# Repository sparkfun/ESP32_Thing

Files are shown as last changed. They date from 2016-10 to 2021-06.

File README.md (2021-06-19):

SparkFun ESP32 Thing
========================================

SparkFun ESP32 Thing (https://www.sparkfun.com/products/13907)

[*SparkFun ESP32 Thing (DEV-13907)*](https://www.sparkfun.com/products/13907)

The [SparkFun ESP32 Thing](https://www.sparkfun.com/products/13907) is a comprehensive development platform for Espressif’s ESP32, their super-charged version of the popular ESP8266. Like the 8266, the ESP32 is a WiFi-compatible microcontroller but adds nearly 30 I/O pins. The ESP32’s power and versatility will make it the foundation of IoT and connected projects for many years to come.

Why the name? We lovingly call it the “Thing” because it's the perfect foundation for your Internet of Things project. The Thing does everything from turning on an LED to posting data with your chosen platform, and can be programmed just like any microcontroller. You can even program the Thing through the Arduino IDE by installing the [ESP32 Arduino Core](https://learn.sparkfun.com/tutorials/esp32-thing-hookup-guide#installing-the-esp32-arduino-core).

The SparkFun ESP32 Thing equips the ESP32 with everything necessary to program, run and develop on the wonderchip. In addition to the WiFi SoC, the Thing includes an FTDI FT231x, which converts USB to serial, and allows your computer to program and communicate with the microcontroller. It also features a LiPo charger, so your ESP32 project can be battery-powered and truly wireless. Additionally, the board includes a handful of LEDs and buttons to aid in your development.

Repository Contents
-------------------

* **/Hardware** - Eagle design files (.brd, .sch)
* **/Production** - Production panel files (.brd)

Documentation
--------------
* **[Hookup Guide](https://learn.sparkfun.com/tutorials/esp32-thing-hookup-guide)** - Basic hookup guide for the ESP32 Thing.
* **[SparkFun Fritzing repo](https://github.com/sparkfun/Fritzing_Parts)** - Fritzing diagrams for SparkFun products.
* **[SparkFun 3D Model repo](https://github.com/sparkfun/3D_Models)** - 3D models of SparkFun products. 
* **[SparkFun Graphical Datasheets](https://github.com/sparkfun/Graphical_Datasheets)** -Graphical Datasheets for various SparkFun products.

Product Versions
----------------
* [DEV-13907](https://www.sparkfun.com/products/13907) - Initial release of the ESP32 Thing.

Version History
---------------
* [V_1.0](https://github.com/sparkfun/ESP32_Thing/releases/tag/V_1.0) - Initial release of the ESP32 Thing

License Information
-------------------

This product is _**open source**_! 

Please review the LICENSE.md file for license information. 

If you have any questions or concerns on licensing, please contact technical support on our [SparkFun forums](https://forum.sparkfun.com/viewforum.php?f=152).

Distributed as-is; no warranty is given.

- Your friends at SparkFun.

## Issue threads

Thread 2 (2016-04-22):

ESP31 Device in sch needs value updated to ESP32

SFE-KADE, 2016-04-22:

ToniCorinne, 2017-02-08:
This board is live. Closing the issue as resolved.

Closed 2017-02-08.

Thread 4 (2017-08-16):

Provide KiCAD modules and library

trycoon, 2017-08-16:
Many DIY builders use Open Source CAD programs (KiCAD for one) instead of licensed programs like Eagle. It would be very nice if there where a KiCAD module and library of Sparkfun ESP32 Thing for us to use! There is a Eagle script plugin that may help converting your existing Eagle schematics to a KiCAD  module/library: https://github.com/lachlanA/eagle-to-kicad
Could you please give it a try, since I don't have a Eagle license to try it myself.
Thanks!

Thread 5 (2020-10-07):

Provide mounting holes

TheChain01, 2020-10-07:
It would be really good if this board could provide some mounting holes in order to secure it in our projects. Right now we would have to solder the board onto another protoboard with mounting holes in order to secure it in place.

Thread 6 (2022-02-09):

Isn't Q1 connected backwards?

kuba2k2, 2022-02-09:
The P-channel MOSFET for switching VIN from USB or battery seems to have its drain and source swapped. This makes the circuit always use the battery voltage, when USB drops below that 4.2V. Since this isn't usually the case, that mostly isn't a problem, but it may occur in some cases, that USB provides such a low voltage that the ESP is powered half from the battery, which may trick the charger into thinking the battery is not fully charged, which may result in overcharging. I am no expert, but I think this is a problem that needs to be fixed.
I was trying to use the voltage switch from the Thing's schematic, implemented it already in my layout and then it came out to be wrong.. without D2, Q1 will always be either saturated or the current will flow through the body diode. Unless that's expected to work this way.

Edit: it's implemented the same way in RP2040 Thing, ESP32-S2, ESP8266 and probably other Things. Please, correct me if I'm wrong (which would be absolutely expected).

Closed 2022-02-09.

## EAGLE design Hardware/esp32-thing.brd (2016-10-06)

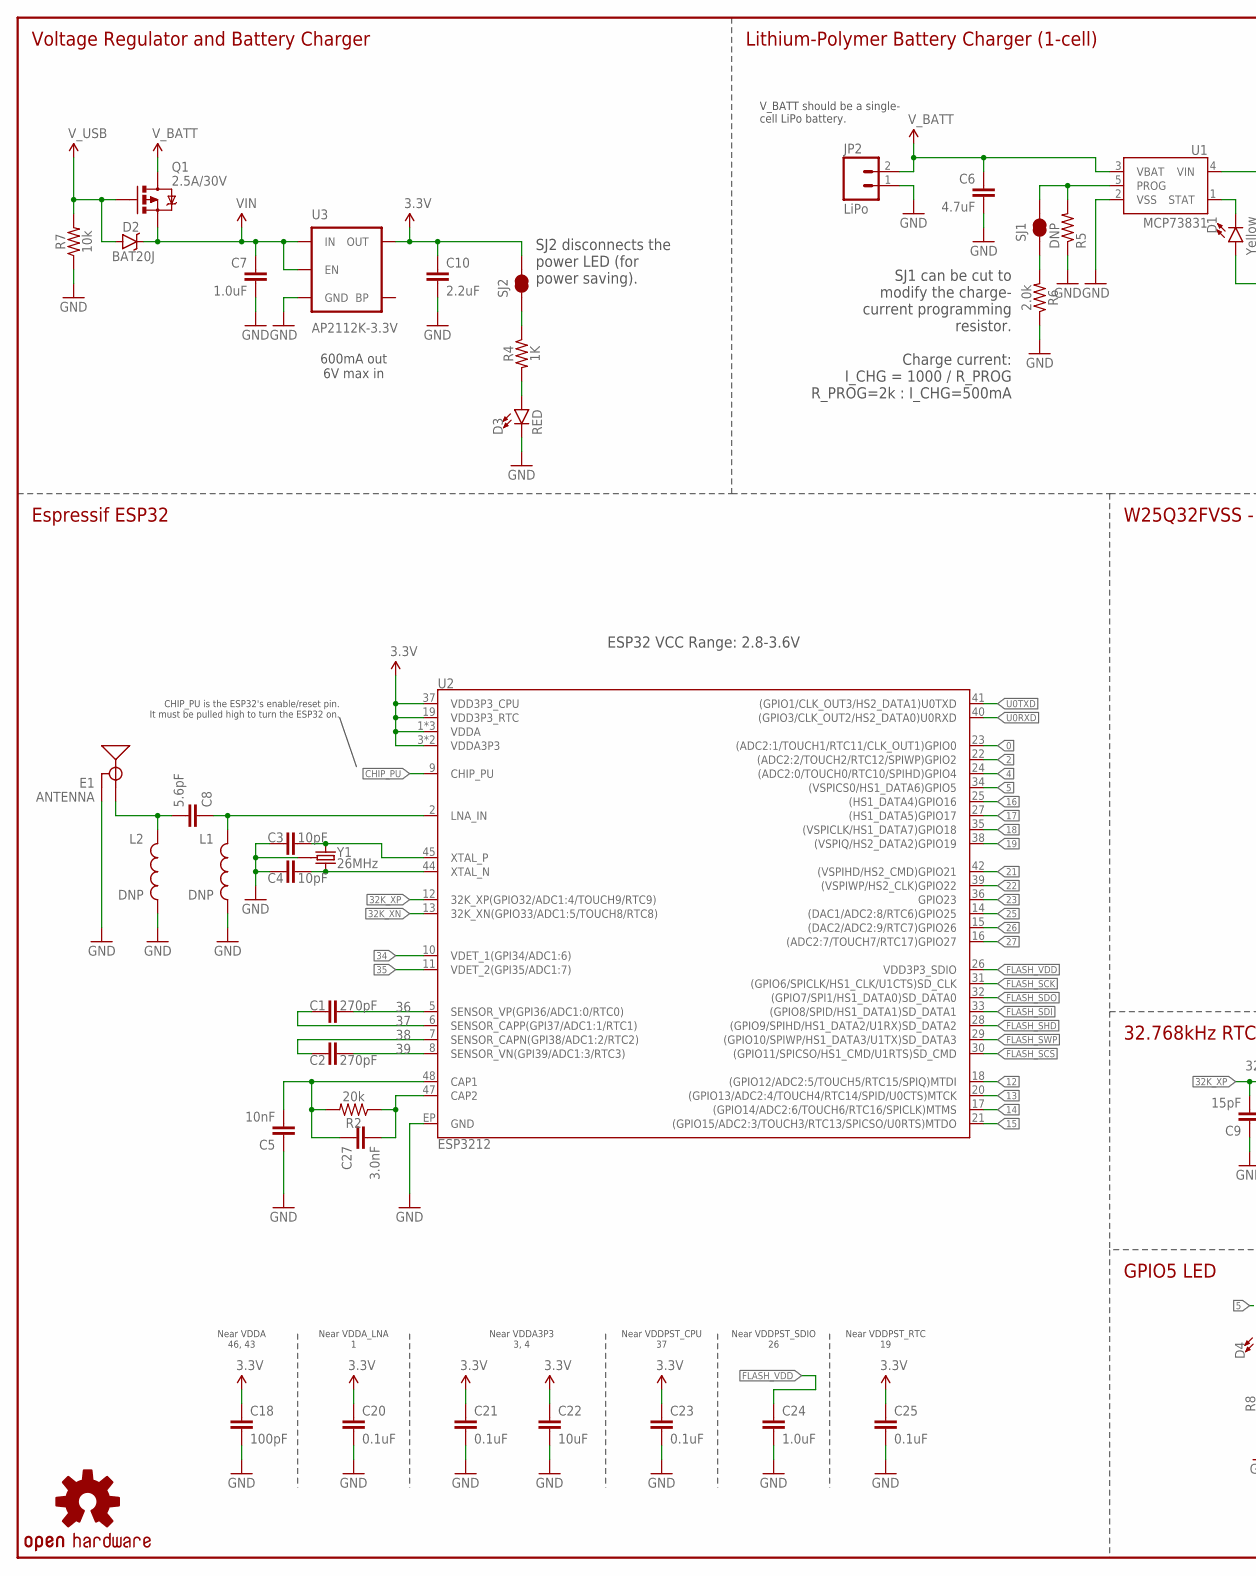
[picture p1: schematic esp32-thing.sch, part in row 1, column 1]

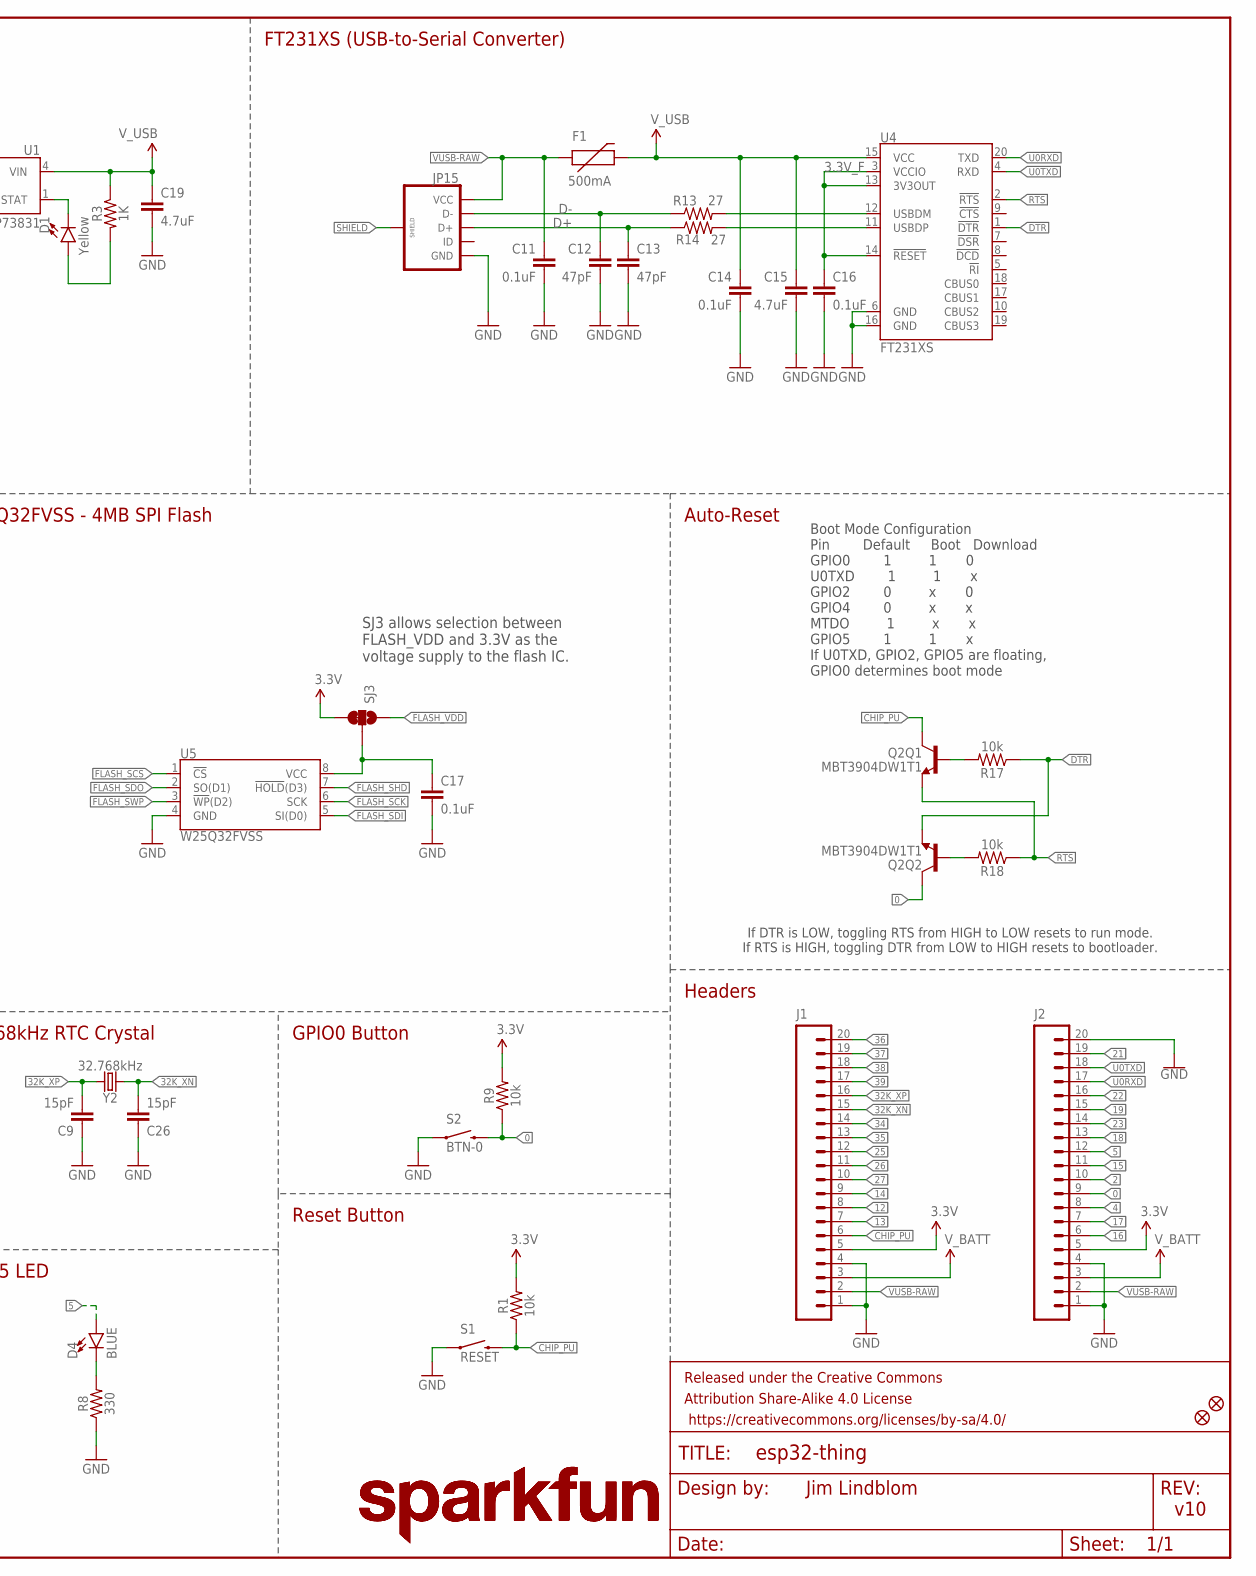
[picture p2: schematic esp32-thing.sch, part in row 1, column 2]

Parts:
C1, C2: 270pF; 0603
C3, C4: 10pF; 0603
C5: 10nF; 0603
C6, C19: 4.7uF; 0603
C7: 1.0uF; 0805
C8: 5.6pF; 0603
C9, C26: 15pF; 0603
C10: 2.2uF; 0603
C11, C14, C16, C17, C20, C21, C23, C25: 0.1uF; 0603
C12, C13: 47pF; 0603
C15: 4.7uF; 0603-CAP
C18: 100pF; 0603
C22: 10uF; 0603
C24: 1.0uF; 0603
C27: 3.0nF; 0603
D1: Yellow; LED-0603
D2: BAT20J; SOD-323
D3: RED; LED-0603
D4: BLUE; LED-0603
E1: ANTENNA; TRACE_ANTENNA_2.4GHZ_25.7MM_TUNED
F1: 500mA; PTC-1206
FD1, FD2: FIDUCIALUFIDUCIAL; MICRO-FIDUCIAL
FRAME1: FRAME-LEDGER; CREATIVE_COMMONS
J1, J2: M20NOSILK; 1X20_NOSILK
JP2: LiPo; JST-2-PTH
JP15: USB_MICROB_PLUGCONN-11752; USB-B-MICRO-SMD_V03
L1, L2: DNP; 0603
LOGO1, LOGO3: SFE_LOGO_NAME.2_INCH; SFE_LOGO_NAME_.2
LOGO2: OSHW-LOGOMINI; OSHW-LOGO-MINI
Q1: 2.5A/30V; SOT23-3
Q2: MBT3904DW1T1; SC70-6
R1, R7, R9, R17, R18: 10k; 0603
R2: 20k; 0603
R3, R4: 1K; 0603
R5: DNP; 1/6W-RES
R6: 2.0k; 0603
R8: 330; 0603
R13, R14: 27; 0603
S1: RESET; TACTILE_SWITCH_SMD_4.6X2.8MM
S2: BTN-0; TACTILE_SWITCH_SMD_4.6X2.8MM
SJ1, SJ2: JUMPER-PAD-2-NC_BY_TRACE; PAD-JUMPER-2-NC_BY_TRACE_YES_SILK
SJ3: JUMPER-PAD-3-2OF3_NC_BY_TRACE_SMALL; PAD-JUMPER-3-2OF3_NC_BY_TRACE_YES_SILK_FULL_BOX
U1: MCP73831; SOT23-5
U2: ESP3212; QFN48-0.4MM
U3: AP2112K-3.3V; SOT23-5
U4: FT231XS; SSOP20_L
U5: W25Q32FVSS; SOIC-8
Y1: 26MHz; CRYSTAL-SMD-3.2X2.5
Y2: 32.768kHz; CRYSTAL-SMD-3.2X1.5MM

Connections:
0: J2.9, Q2.6 (C), R9.1, S2.3 (2), S2.4 (2), U2.23 ((ADC2:1/TOUCH1/RTC11/CLK_OUT1)GPIO0)
2: J2.10, U2.22 ((ADC2:2/TOUCH2/RTC12/SPIWP)GPIO2)
3.3V: C10.1, C18.1, C20.1, C21.1, C22.1, C23.1, C25.1, J1.5, J2.5, R1.2, R9.2, SJ2.2, SJ3.3, U2.1 (VDDA), U2.3 (VDDA3P3), U2.4 (VDDA3P3), U2.19 (VDD3P3_RTC), U2.37 (VDD3P3_CPU), U2.43 (VDDA), U2.46 (VDDA), U3.5 (OUT)
3.3V_F: C16.1, U4.3 (VCCIO), U4.13 (3V3OUT), U4.14 (!RESET)
4: J2.8, U2.24 ((ADC2:0/TOUCH0/RTC10/SPIHD)GPIO4)
5: D4.A, J2.12, U2.34 ((VSPICS0/HS1_DATA6)GPIO5)
12: J1.8, U2.18 ((GPIO12/ADC2:5/TOUCH5/RTC15/SPIQ)MTDI)
13: J1.7, U2.20 ((GPIO13/ADC2:4/TOUCH4/RTC14/SPID/U0CTS)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)
14: J1.9, U2.17 ((GPIO14/ADC2:6/TOUCH6/RTC16/SPICLK)MTMS)
15: J2.11, U2.21 ((GPIO15/ADC2:3/TOUCH3/RTC13/SPICSO/U0RT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)
16: J2.6, U2.25 ((HS1_DATA4)GPIO16)
17: J2.7, U2.27 ((HS1_DATA5)GPIO17)
18: J2.13, U2.35 ((VSPICLK/HS1_DATA7)GPIO18)
19: J2.15, U2.38 ((VSPIQ/HS2_DATA2)GPIO19)
21: J2.19, U2.42 ((VSPIHD/HS2_CMD)GPIO21)
22: J2.16, U2.39 ((VSPIWP/HS2_CLK)GPIO22)
23: J2.14, U2.36 (GPIO23)
25: J1.12, U2.14 ((DAC1/ADC2:8/RTC6)GPIO25)
26: J1.11, U2.15 ((DAC2/ADC2:9/RTC7)GPIO26)
27: J1.10, U2.16 ((ADC2:7/TOUCH7/RTC17)GPIO27)
32K_XN: C26.2, J1.15, U2.13 (32K_XN(GPIO33/ADC1:5/TOUCH8/RTC8)), Y2.P$2 (2)
32K_XP: C9.2, J1.16, U2.12 (32K_XP(GPIO32/ADC1:4/TOUCH9/RTC9)), Y2.P$1 (1)
34: J1.14, U2.10 (VDET_1(GPI34/ADC1:6))
35: J1.13, U2.11 (VDET_2(GPI35/ADC1:7))
36: C1.2, J1.20, U2.5 (SENSOR_VP(GPI36/ADC1:0/RTC0))
37: C1.1, J1.19, U2.6 (SENSOR_CAPP(GPI37/ADC1:1/RTC1))
38: C2.1, J1.18, U2.7 (SENSOR_CAPN(GPI38/ADC1:2/RTC2))
39: C2.2, J1.17, U2.8 (SENSOR_VN(GPI39/ADC1:3/RTC3))
CAP_10N: C5.2, C27.1, R2.2, U2.48 (CAP1)
CHIP_PU: J1.6, Q2.3 (C), R1.1, S1.3 (2), S1.4 (2), U2.9 (CHIP_PU)
D+: C13.1, JP15.D+, R14.1
D-: C12.1, JP15.D-, R13.1
DTR: Q2.1 (E), R17.1, U4.1 (!DTR)
FLASH_SCK: U2.31 ((GPIO6/SPICLK/HS1_CLK/U1CTS)SD_CLK), U5.6 (SCK)
FLASH_SCS: U2.30 ((GPIO11/SPICSO/HS1_CMD/U1RTS)SD_CMD), U5.1 (!CS!)
FLASH_SDI: U2.33 ((GPIO8/SPID/HS1_DATA1)SD_DATA1), U5.5 (SI(D0))
FLASH_SDO: U2.32 ((GPIO7/SPI1/HS1_DATA0)SD_DATA0), U5.2 (SO(D1))
FLASH_SHD: U2.28 ((GPIO9/SPIHD/HS1_DATA2/U1RX)SD_DATA2), U5.7 (!HOLD!(D3))
FLASH_SWP: U2.29 ((GPIO10/SPIWP/HS1_DATA3/U1TX)SD_DATA3), U5.3 (!WP!(D2))
FLASH_VDD: C24.1, SJ3.1, U2.26 (VDD3P3_SDIO)
GND: C3.1, C4.1, C5.1, C6.2, C7.2, C9.1, C10.2, C11.2, C12.2, C13.2, C14.2, C15.2, C16.2, C17.2, C18.2, C19.2, C20.2, C21.2, C22.2, C23.2, C24.2, C25.2, C26.1, D3.C, E1.GND, E1.GND2 (GND), J1.1, J1.4, J2.1, J2.4, J2.20, JP2.1, JP15.GND, L1.2, L2.2, R5.1, R6.1, R7.1, R8.1, S1.1, S1.2 (1), S2.1, S2.2 (1), U1.2 (VSS), U2.EP (GND), U3.2 (GND), U4.6 (GND), U4.16 (GND), U5.4 (GND), Y1.2 (GND), Y1.4 (GND)
LNA_IN: C8.1, L1.1, U2.2 (LNA_IN)
unnamed: D4.C, R8.2
unnamed: D3.A, R4.2
unnamed: R4.1, SJ2.1
unnamed: C27.2, R2.1, U2.47 (CAP2)
unnamed: R13.2, U4.12 (USBDM)
unnamed: R14.2, U4.11 (USBDP)
unnamed: D1.C, U1.1 (STAT)
unnamed: Q2.5 (B), R17.2
unnamed: C17.1, SJ3.2, U5.8 (VCC)
unnamed: Q2.2 (B), R18.2
unnamed: C3.2, U2.45 (XTAL_P), Y1.1
unnamed: R5.2, SJ1.2, U1.5 (PROG)
unnamed: C4.2, U2.44 (XTAL_N), Y1.3 (2)
unnamed: R6.2, SJ1.1
unnamed: D1.A, R3.2
RTS: Q2.4 (E), R18.1, U4.2 (!RTS)
SHIELD: JP15.SHIELD1 (SHIELD), JP15.SHIELD2 (SHIELD), JP15.SHIELD3 (SHIELD)
TRACE_ANT: C8.2, E1.ANT (SIGNAL), L2.1
U0RXD: J2.17, U2.40 ((GPIO3/CLK_OUT2/HS2_DATA0)U0RXD), U4.20 (TXD)
U0TXD: J2.18, U2.41 ((GPIO1/CLK_OUT3/HS2_DATA1)U0TXD), U4.4 (RXD)
VIN: C7.1, D2.C, Q1.2 (S), U3.1 (IN), U3.3 (EN)
VUSB-RAW: C11.1, F1.1, J1.2, J2.2, JP15.VBUS (VCC)
V_BATT: C6.1, J1.3, J2.3, JP2.2, Q1.3 (D), U1.3 (VBAT)
V_USB: C14.1, C15.1, C19.1, D2.A, F1.2, Q1.1 (G), R3.1, R7.2, U1.4 (VIN), U4.15 (VCC)

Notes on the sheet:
Boot Mode Configuration Pin Default Boot Download GPIO0 1 1 0 U0TXD 1 1 x GPIO2 0 x 0 GPIO4 0 x x MTDO 1 x x GPIO5 1 1 x If U0TXD, GPIO2, GPIO5 are floating, GPIO0 determines boot mode
FT231XS (USB-to-Serial Converter)
V_BATT should be a single- cell LiPo battery.
Charge current: I_CHG = 1000 / R_PROG R_PROG=2k : I_CHG=500mA
Voltage Regulator and Battery Charger
SJ1 can be cut to modify the charge- current programming resistor.
Lithium-Polymer Battery Charger (1-cell)
600mA out 6V max in
Auto-Reset
Near VDDA 46, 43
Near VDDA_LNA 1
Near VDDA3P3 3, 4
Near VDDPST_CPU 37
Near VDDPST_SDIO 26
Near VDDPST_RTC 19
Espressif ESP32
W25Q32FVSS - 4MB SPI Flash
32.768kHz RTC Crystal
GPIO0 Button
Reset Button
GPIO5 LED
Headers
v10
Jim Lindblom
ESP32 VCC Range: 2.8-3.6V
SJ3 allows selection between FLASH_VDD and 3.3V as the voltage supply to the flash IC.
SJ2 disconnects the power LED (for power saving).
If DTR is LOW, toggling RTS from HIGH to LOW resets to run mode. If RTS is HIGH, toggling DTR from LOW to HIGH resets to bootloader.
CHIP_PU is the ESP32's enable/reset pin. It must be pulled high to turn the ESP32 on.

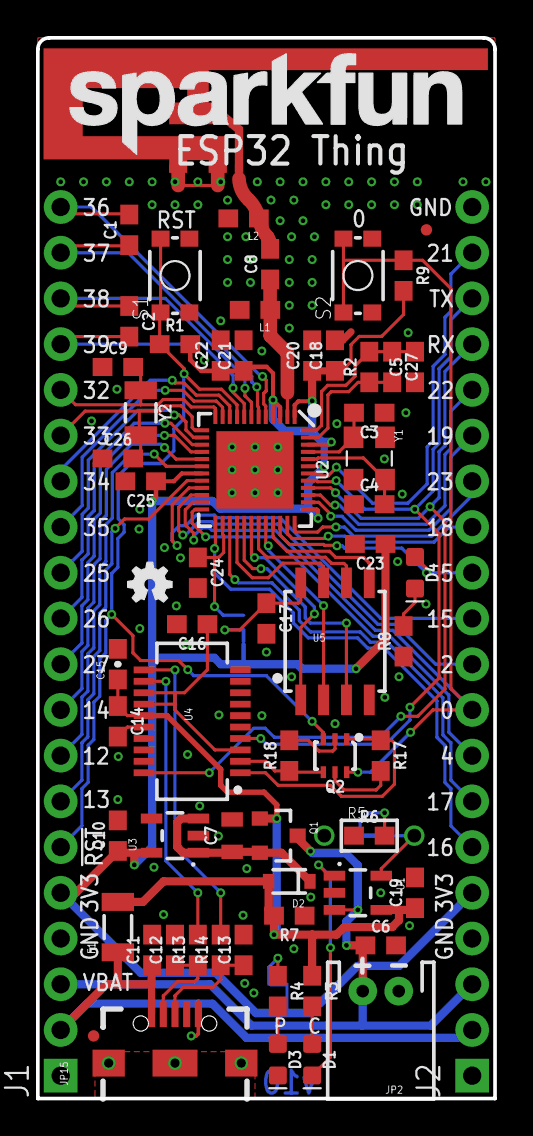
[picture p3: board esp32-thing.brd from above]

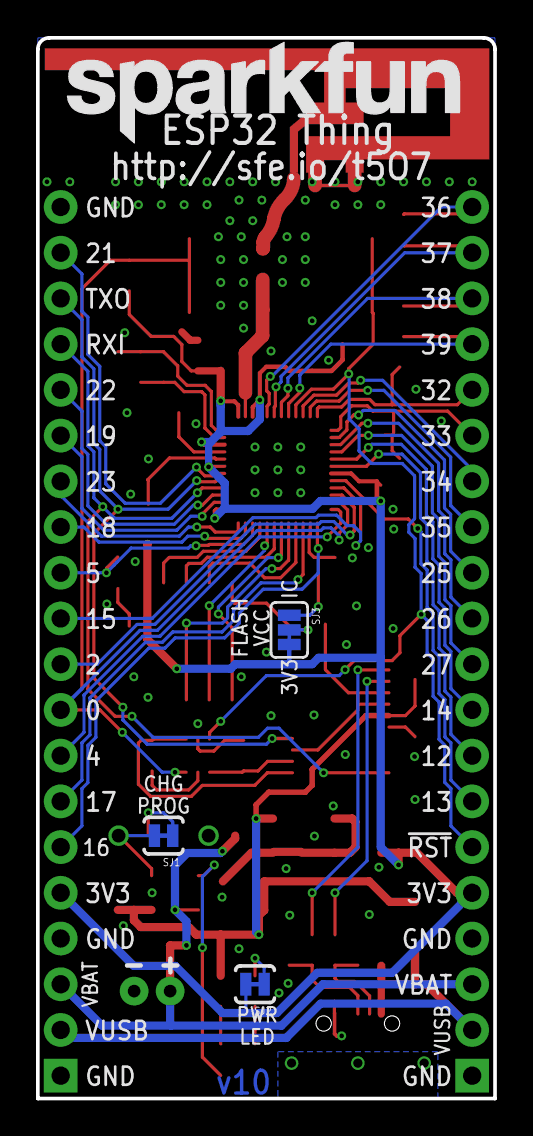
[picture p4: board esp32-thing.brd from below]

Board: 2 copper layers, 25.4 x 58.9 mm, 72 parts (4 on the bottom side), 66 nets.

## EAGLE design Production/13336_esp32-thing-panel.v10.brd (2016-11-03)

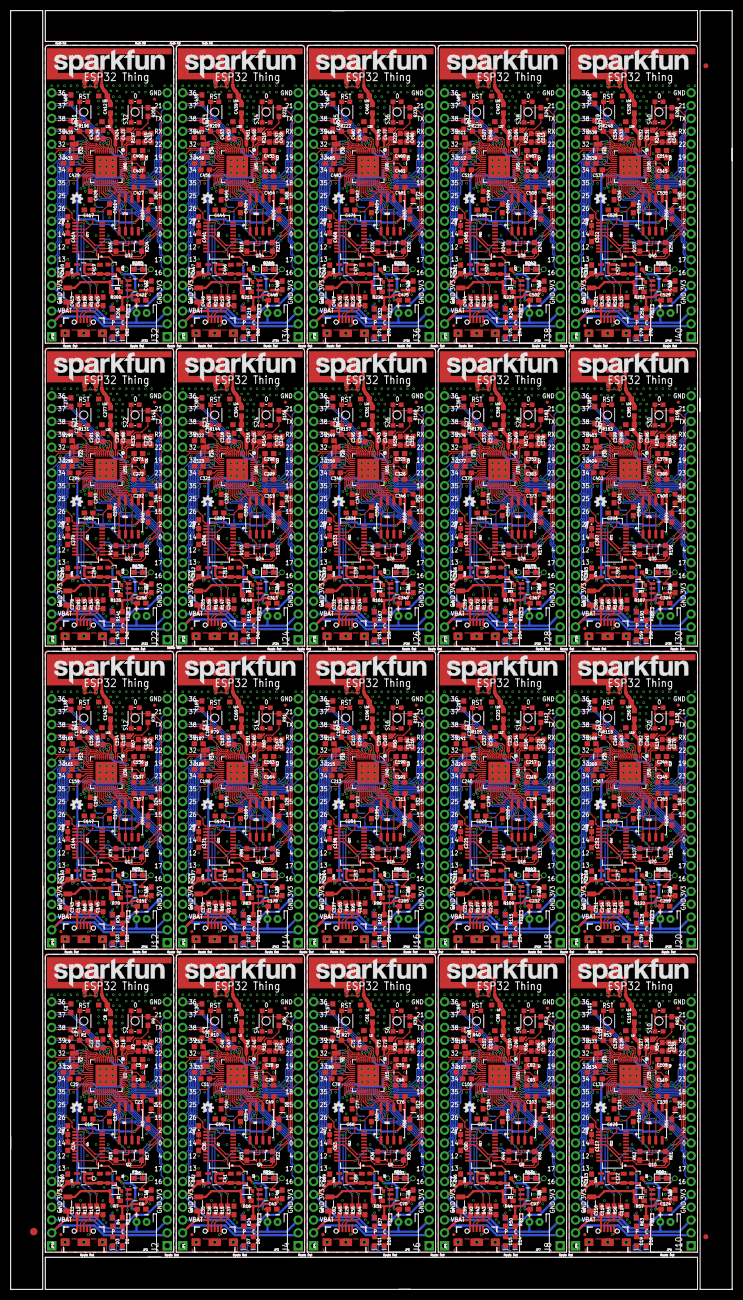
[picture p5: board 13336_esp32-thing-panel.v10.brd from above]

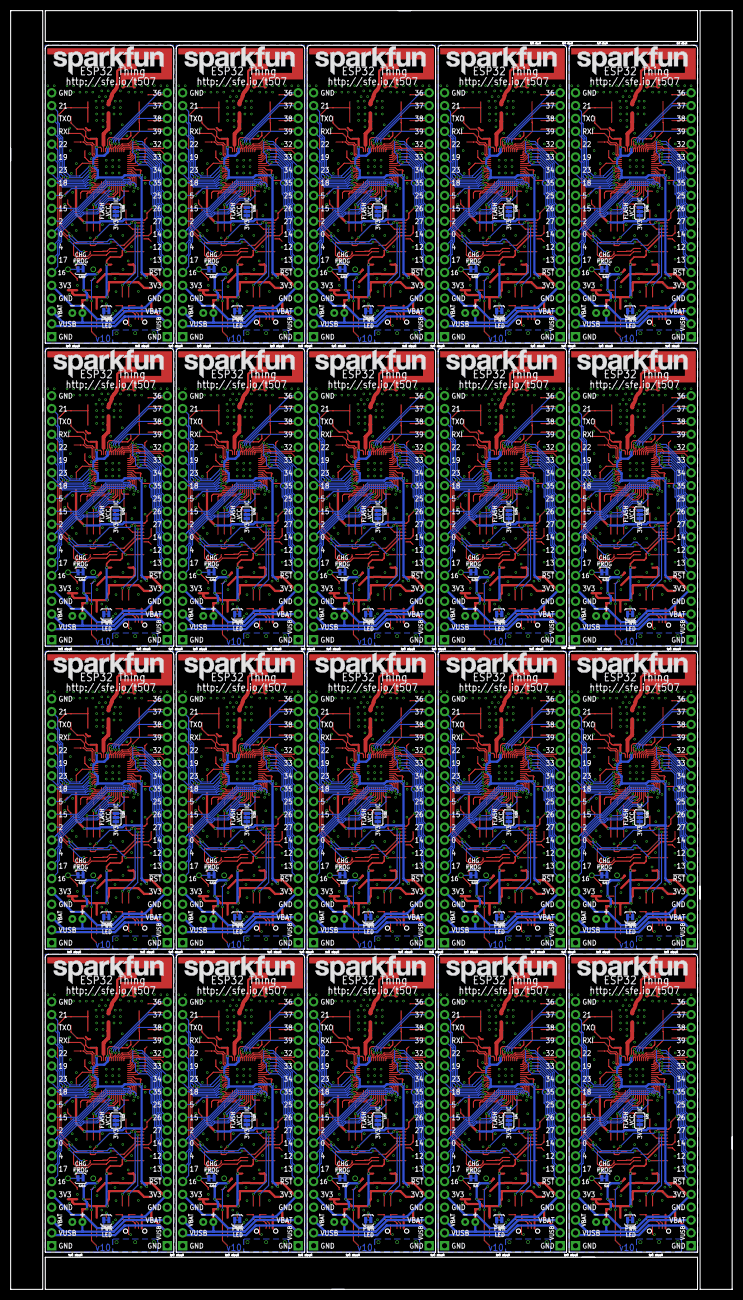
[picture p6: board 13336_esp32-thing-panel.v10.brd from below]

Board: 2 copper layers, 142.7 x 253.0 mm, 1423 parts (80 on the bottom side), 1320 nets.

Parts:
C1, C2, C30, C31, C57, C58, C84, C85, C111, C112, C138, C139, C165, C166, C192, C193, C219, C220, C246, C247, C273, C274, C300, C301, C327, C328, C354, C355, C381, C382, C408, C409, C435, C436, C462, C463, C489, C490, C516, C517: 270pF; 0603
C3, C4, C28, C29, C55, C56, C82, C83, C109, C110, C136, C137, C163, C164, C190, C191, C217, C218, C244, C245, C271, C272, C298, C299, C325, C326, C352, C353, C379, C380, C406, C407, C433, C434, C460, C461, C487, C488, C514, C515: 10pF; 0603
C5, C32, C59, C86, C113, C140, C167, C194, C221, C248, C275, C302, C329, C356, C383, C410, C437, C464, C491, C518: 10nF; 0603
C6, C19, C43, C44, C70, C71, C97, C98, C124, C125, C151, C152, C178, C179, C205, C206, C232, C233, C259, C260, C286, C287, C313, C314, C340, C341, C367, C368, C394, C395, C421, C422, C448, C449, C475, C476, C502, C503, C529, C530: 4.7uF; 0603
C7, C41, C68, C95, C122, C149, C176, C203, C230, C257, C284, C311, C338, C365, C392, C419, C446, C473, C500, C527: 1.0uF; 0805
C8, C34, C61, C88, C115, C142, C169, C196, C223, C250, C277, C304, C331, C358, C385, C412, C439, C466, C493, C520: 5.6pF; 0603
C9, C26, C52, C53, C79, C80, C106, C107, C133, C134, C160, C161, C187, C188, C214, C215, C241, C242, C268, C269, C295, C296, C322, C323, C349, C350, C376, C377, C403, C404, C430, C431, C457, C458, C484, C485, C511, C512, C538, C539: 15pF; 0603
C10, C42, C69, C96, C123, C150, C177, C204, C231, C258, C285, C312, C339, C366, C393, C420, C447, C474, C501, C528: 2.2uF; 0603
C11, C14, C16, C17, C20, C21, C23, C25, C33, C35, C36, C39, C46, C47, C49, C51, C60, C62, C63, C66, C73, C74, C76, C78, C87, C89, C90, C93, C100, C101, C103, C105, C114, C116, C117, C120, C127, C128, C130, C132, C141, C143, C144, C147, C154, C155, C157, C159, C168, C170, C171, C174, C181, C182, C184, C186, C195, C197, C198, C201, C208, C209, C211, C213, C222, C224, C225, C228, C235, C236, C238, C240, C249, C251, C252, C255, C262, C263, C265, C267, C276, C278, C279, C282, C289, C290, C292, C294, C303, C305, C306, C309, C316, C317, C319, C321, C330, C332, C333, C336, C343, C344, C346, C348, C357, C359, C360, C363, C370, C371, C373, C375, C384, C386, C387, C390, C397, C398, C400, C402, C411, C413, C414, C417, C424, C425, C427, C429, C438, C440, C441, C444, C451, C452, C454, C456, C465, C467, C468, C471, C478, C479, C481, C483, C492, C494, C495, C498, C505, C506, C508, C510, C519, C521, C522, C525, C532, C533, C535, C537: 0.1uF; 0603
C12, C13, C37, C38, C64, C65, C91, C92, C118, C119, C145, C146, C172, C173, C199, C200, C226, C227, C253, C254, C280, C281, C307, C308, C334, C335, C361, C362, C388, C389, C415, C416, C442, C443, C469, C470, C496, C497, C523, C524: 47pF; 0603
C15, C40, C67, C94, C121, C148, C175, C202, C229, C256, C283, C310, C337, C364, C391, C418, C445, C472, C499, C526: 4.7uF; 0603-CAP
C18, C45, C72, C99, C126, C153, C180, C207, C234, C261, C288, C315, C342, C369, C396, C423, C450, C477, C504, C531: 100pF; 0603
C22, C48, C75, C102, C129, C156, C183, C210, C237, C264, C291, C318, C345, C372, C399, C426, C453, C480, C507, C534: 10uF; 0603
C24, C50, C77, C104, C131, C158, C185, C212, C239, C266, C293, C320, C347, C374, C401, C428, C455, C482, C509, C536: 1.0uF; 0603
C27, C54, C81, C108, C135, C162, C189, C216, C243, C270, C297, C324, C351, C378, C405, C432, C459, C486, C513, C540: 3.0nF; 0603
D1, D6, D10, D14, D18, D22, D26, D30, D34, D38, D42, D46, D50, D54, D58, D62, D66, D70, D74, D78: Yellow; LED-0603
D2, D5, D9, D13, D17, D21, D25, D29, D33, D37, D41, D45, D49, D53, D57, D61, D65, D69, D73, D77: BAT20J; SOD-323
D3, D7, D11, D15, D19, D23, D27, D31, D35, D39, D43, D47, D51, D55, D59, D63, D67, D71, D75, D79: RED; LED-0603
D4, D8, D12, D16, D20, D24, D28, D32, D36, D40, D44, D48, D52, D56, D60, D64, D68, D72, D76, D80: BLUE; LED-0603
E1, E2, E3, E4, E5, E6, E7, E8, E9, E10, E11, E12, E13, E14, E15, E16, E17, E18, E19, E20: ANTENNA; TRACE_ANTENNA_2.4GHZ_25.7MM_TUNED
E$1: FIDUCIAL-1.5X3
E$7, E$8: FIDUCIAL-1X2
F1, F2, F3, F4, F5, F6, F7, F8, F9, F10, F11, F12, F13, F14, F15, F16, F17, F18, F19, F20: 500mA; PTC-1206
FD1, FD2, FD3, FD4, FD5, FD6, FD7, FD8, FD9, FD10, FD11, FD12, FD13, FD14, FD15, FD16, FD17, FD18, FD19, FD20, FD21, FD22, FD23, FD24, FD25, FD26, FD27, FD28, FD29, FD30, FD31, FD32, FD33, FD34, FD35, FD36, FD37, FD38, FD39, FD40: FIDUCIALUFIDUCIAL; MICRO-FIDUCIAL
J1, J2, J3, J4, J5, J6, J7, J8, J9, J10, J11, J12, J13, J14, J15, J16, J17, J18, J19, J20, J21, J22, J23, J24, J25, J26, J27, J28, J29, J30, J31, J32, J33, J34, J35, J36, J37, J38, J39, J40: 1X20_NOSILK
JP1, JP4, JP6, JP8, JP10, JP12, JP14, JP15, JP17, JP19, JP21, JP23, JP25, JP27, JP29, JP31, JP33, JP35, JP37, JP39: USB-B-MICRO-SMD_V03
JP2, JP3, JP5, JP7, JP9, JP11, JP13, JP16, JP18, JP20, JP22, JP24, JP26, JP28, JP30, JP32, JP34, JP36, JP38, JP40: LiPo; JST-2-PTH
L1, L2, L3, L4, L5, L6, L7, L8, L9, L10, L11, L12, L13, L14, L15, L16, L17, L18, L19, L20, L21, L22, L23, L24, L25, L26, L27, L28, L29, L30, L31, L32, L33, L34, L35, L36, L37, L38, L39, L40: DNP; 0603
LOGO1, LOGO3, LOGO4, LOGO6, LOGO7, LOGO9, LOGO10, LOGO12, LOGO13, LOGO15, LOGO16, LOGO18, LOGO19, LOGO21, LOGO22, LOGO24, LOGO25, LOGO27, LOGO28, LOGO30, LOGO31, LOGO33, LOGO34, LOGO36, LOGO37, LOGO39, LOGO40, LOGO42, LOGO43, LOGO45, LOGO46, LOGO48, LOGO49, LOGO51, LOGO52, LOGO54, LOGO55, LOGO57, LOGO58, LOGO60: SFE_LOGO_NAME.2_INCH; SFE_LOGO_NAME_.2
LOGO2, LOGO5, LOGO8, LOGO11, LOGO14, LOGO17, LOGO20, LOGO23, LOGO26, LOGO29, LOGO32, LOGO35, LOGO38, LOGO41, LOGO44, LOGO47, LOGO50, LOGO53, LOGO56, LOGO59: OSHW-LOGOMINI; OSHW-LOGO-MINI
Q1, Q3, Q5, Q7, Q9, Q11, Q13, Q15, Q17, Q19, Q21, Q23, Q25, Q27, Q29, Q31, Q33, Q35, Q37, Q39: 2.5A/30V; SOT23-3
Q2, Q4, Q6, Q8, Q10, Q12, Q14, Q16, Q18, Q20, Q22, Q24, Q26, Q28, Q30, Q32, Q34, Q36, Q38, Q40: MBT3904DW1T1; SC70-6
R1, R7, R9, R10, R16, R17, R18, R22, R23, R26, R27, R31, R35, R36, R39, R40, R44, R48, R49, R52, R53, R57, R61, R62, R65, R66, R70, R74, R75, R78, R79, R83, R87, R88, R91, R92, R96, R100, R101, R104, R105, R109, R113, R114, R117, R118, R122, R126, R127, R130, R131, R135, R139, R140, R143, R144, R148, R152, R153, R156, R157, R161, R165, R166, R169, R170, R174, R178, R179, R182, R183, R187, R191, R192, R195, R196, R200, R204, R205, R208, R209, R213, R217, R218, R221, R222, R226, R230, R231, R234, R235, R239, R243, R244, R247, R248, R252, R256, R257, R260: 10k; 0603
R2, R11, R28, R41, R54, R67, R80, R93, R106, R119, R132, R145, R158, R171, R184, R197, R210, R223, R236, R249: 20k; 0603
R3, R4, R19, R24, R32, R37, R45, R50, R58, R63, R71, R76, R84, R89, R97, R102, R110, R115, R123, R128, R136, R141, R149, R154, R162, R167, R175, R180, R188, R193, R201, R206, R214, R219, R227, R232, R240, R245, R253, R258: 1K; 0603
R5, R21, R34, R47, R60, R73, R86, R99, R112, R125, R138, R151, R164, R177, R190, R203, R216, R229, R242, R255: DNP; 1/6W-RES
R6, R20, R33, R46, R59, R72, R85, R98, R111, R124, R137, R150, R163, R176, R189, R202, R215, R228, R241, R254: 2.0k; 0603
R8, R25, R38, R51, R64, R77, R90, R103, R116, R129, R142, R155, R168, R181, R194, R207, R220, R233, R246, R259: 330; 0603
R12, R13, R14, R15, R29, R30, R42, R43, R55, R56, R68, R69, R81, R82, R94, R95, R107, R108, R120, R121, R133, R134, R146, R147, R159, R160, R172, R173, R185, R186, R198, R199, R211, R212, R224, R225, R237, R238, R250, R251: 27; 0603
S1, S3, S5, S7, S9, S11, S13, S15, S17, S19, S21, S23, S25, S27, S29, S31, S33, S35, S37, S39: RESET; TACTILE_SWITCH_SMD_4.6X2.8MM
S2, S4, S6, S8, S10, S12, S14, S16, S18, S20, S22, S24, S26, S28, S30, S32, S34, S36, S38, S40: BTN-0; TACTILE_SWITCH_SMD_4.6X2.8MM
SJ1, SJ2, SJ5, SJ6, SJ8, SJ9, SJ11, SJ12, SJ14, SJ15, SJ17, SJ18, SJ20, SJ21, SJ23, SJ24, SJ26, SJ27, SJ29, SJ30, SJ32, SJ33, SJ35, SJ36, SJ38, SJ39, SJ41, SJ42, SJ44, SJ45, SJ47, SJ48, SJ50, SJ51, SJ53, SJ54, SJ56, SJ57, SJ59, SJ60: JUMPER-PAD-2-NC_BY_TRACE; PAD-JUMPER-2-NC_BY_TRACE_YES_SILK
SJ3, SJ4, SJ7, SJ10, SJ13, SJ16, SJ19, SJ22, SJ25, SJ28, SJ31, SJ34, SJ37, SJ40, SJ43, SJ46, SJ49, SJ52, SJ55, SJ58: PAD-JUMPER-3-2OF3_NC_BY_TRACE_YES_SILK_FULL_BOX
U1, U8, U13, U18, U23, U28, U33, U38, U43, U48, U53, U58, U63, U68, U73, U78, U83, U88, U93, U98: MCP73831; SOT23-5
U2, U10, U15, U20, U25, U30, U35, U40, U45, U50, U55, U60, U65, U70, U75, U80, U85, U90, U95, U100: ESP3212; QFN48-0.4MM
U3, U9, U14, U19, U24, U29, U34, U39, U44, U49, U54, U59, U64, U69, U74, U79, U84, U89, U94, U99: AP2112K-3.3V; SOT23-5
U4, U7, U12, U17, U22, U27, U32, U37, U42, U47, U52, U57, U62, U67, U72, U77, U82, U87, U92, U97: FT231XS; SSOP20_L
U5, U6, U11, U16, U21, U26, U31, U36, U41, U46, U51, U56, U61, U66, U71, U76, U81, U86, U91, U96: W25Q32FVSS; SOIC-8
Y1, Y3, Y5, Y7, Y9, Y11, Y13, Y15, Y17, Y19, Y21, Y23, Y25, Y27, Y29, Y31, Y33, Y35, Y37, Y39: 26MHz; CRYSTAL-SMD-3.2X2.5
Y2, Y4, Y6, Y8, Y10, Y12, Y14, Y16, Y18, Y20, Y22, Y24, Y26, Y28, Y30, Y32, Y34, Y36, Y38, Y40: 32.768kHz; CRYSTAL-SMD-3.2X1.5MM

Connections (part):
0: J2.9, Q2.6, R9.1, S2.3, S2.4, U2.23
1: J3.14, U10.10
2: J2.10, U2.22
3: J3.13, U10.11
3.3V: C10.1, C18.1, C20.1, C21.1, C22.1, C23.1, C25.1, J1.5, J2.5, R1.2, R9.2, SJ2.2, SJ3.3, U2.1, U2.3, U2.4, U2.19, U2.37, U2.43, U2.46, U3.5
3.3V1: C42.1, C45.1, C46.1, C47.1, C48.1, C49.1, C51.1, J3.5, J4.5, R10.2, R26.2, SJ4.3, SJ6.2, U9.5, U10.1, U10.3, U10.4, U10.19, U10.37, U10.43, U10.46
3.3V2: C69.1, C72.1, C73.1, C74.1, C75.1, C76.1, C78.1, J5.5, J6.5, R27.2, R39.2, SJ7.3, SJ9.2, U14.5, U15.1, U15.3, U15.4, U15.19, U15.37, U15.43, U15.46
3.3V3: C96.1, C99.1, C100.1, C101.1, C102.1, C103.1, C105.1, J7.5, J8.5, R40.2, R52.2, SJ10.3, SJ12.2, U19.5, U20.1, U20.3, U20.4, U20.19, U20.37, U20.43, U20.46
3.3V4: C123.1, C126.1, C127.1, C128.1, C129.1, C130.1, C132.1, J9.5, J10.5, R53.2, R65.2, SJ13.3, SJ15.2, U24.5, U25.1, U25.3, U25.4, U25.19, U25.37, U25.43, U25.46
3.3V5: C150.1, C153.1, C154.1, C155.1, C156.1, C157.1, C159.1, J11.5, J12.5, R66.2, R78.2, SJ16.3, SJ18.2, U29.5, U30.1, U30.3, U30.4, U30.19, U30.37, U30.43, U30.46
3.3V6: C177.1, C180.1, C181.1, C182.1, C183.1, C184.1, C186.1, J13.5, J14.5, R79.2, R91.2, SJ19.3, SJ21.2, U34.5, U35.1, U35.3, U35.4, U35.19, U35.37, U35.43, U35.46
3.3V7: C204.1, C207.1, C208.1, C209.1, C210.1, C211.1, C213.1, J15.5, J16.5, R92.2, R104.2, SJ22.3, SJ24.2, U39.5, U40.1, U40.3, U40.4, U40.19, U40.37, U40.43, U40.46
3.3V8: C231.1, C234.1, C235.1, C236.1, C237.1, C238.1, C240.1, J17.5, J18.5, R105.2, R117.2, SJ25.3, SJ27.2, U44.5, U45.1, U45.3, U45.4, U45.19, U45.37, U45.43, U45.46
3.3V9: C258.1, C261.1, C262.1, C263.1, C264.1, C265.1, C267.1, J19.5, J20.5, R118.2, R130.2, SJ28.3, SJ30.2, U49.5, U50.1, U50.3, U50.4, U50.19, U50.37, U50.43, U50.46
3.3V10: C285.1, C288.1, C289.1, C290.1, C291.1, C292.1, C294.1, J21.5, J22.5, R131.2, R143.2, SJ31.3, SJ33.2, U54.5, U55.1, U55.3, U55.4, U55.19, U55.37, U55.43, U55.46
3.3V11: C312.1, C315.1, C316.1, C317.1, C318.1, C319.1, C321.1, J23.5, J24.5, R144.2, R156.2, SJ34.3, SJ36.2, U59.5, U60.1, U60.3, U60.4, U60.19, U60.37, U60.43, U60.46
3.3V12: C339.1, C342.1, C343.1, C344.1, C345.1, C346.1, C348.1, J25.5, J26.5, R157.2, R169.2, SJ37.3, SJ39.2, U64.5, U65.1, U65.3, U65.4, U65.19, U65.37, U65.43, U65.46
3.3V13: C366.1, C369.1, C370.1, C371.1, C372.1, C373.1, C375.1, J27.5, J28.5, R170.2, R182.2, SJ40.3, SJ42.2, U69.5, U70.1, U70.3, U70.4, U70.19, U70.37, U70.43, U70.46
3.3V14: C393.1, C396.1, C397.1, C398.1, C399.1, C400.1, C402.1, J29.5, J30.5, R183.2, R195.2, SJ43.3, SJ45.2, U74.5, U75.1, U75.3, U75.4, U75.19, U75.37, U75.43, U75.46
3.3V15: C420.1, C423.1, C424.1, C425.1, C426.1, C427.1, C429.1, J31.5, J32.5, R196.2, R208.2, SJ46.3, SJ48.2, U79.5, U80.1, U80.3, U80.4, U80.19, U80.37, U80.43, U80.46
3.3V16: C447.1, C450.1, C451.1, C452.1, C453.1, C454.1, C456.1, J33.5, J34.5, R209.2, R221.2, SJ49.3, SJ51.2, U84.5, U85.1, U85.3, U85.4, U85.19, U85.37, U85.43, U85.46
3.3V17: C474.1, C477.1, C478.1, C479.1, C480.1, C481.1, C483.1, J35.5, J36.5, R222.2, R234.2, SJ52.3, SJ54.2, U89.5, U90.1, U90.3, U90.4, U90.19, U90.37, U90.43, U90.46
3.3V18: C501.1, C504.1, C505.1, C506.1, C507.1, C508.1, C510.1, J37.5, J38.5, R235.2, R247.2, SJ55.3, SJ57.2, U94.5, U95.1, U95.3, U95.4, U95.19, U95.37, U95.43, U95.46
3.3V19: C528.1, C531.1, C532.1, C533.1, C534.1, C535.1, C537.1, J39.5, J40.5, R248.2, R260.2, SJ58.3, SJ60.2, U99.5, U100.1, U100.3, U100.4, U100.19, U100.37, U100.43, U100.46
3.3V_F: C16.1, U4.3, U4.13, U4.14
3.3V_F1: C39.1, U7.3, U7.13, U7.14
3.3V_F2: C66.1, U12.3, U12.13, U12.14
3.3V_F3: C93.1, U17.3, U17.13, U17.14
3.3V_F4: C120.1, U22.3, U22.13, U22.14
3.3V_F5: C147.1, U27.3, U27.13, U27.14
3.3V_F6: C174.1, U32.3, U32.13, U32.14
3.3V_F7: C201.1, U37.3, U37.13, U37.14
3.3V_F8: C228.1, U42.3, U42.13, U42.14
3.3V_F9: C255.1, U47.3, U47.13, U47.14
3.3V_F10: C282.1, U52.3, U52.13, U52.14
3.3V_F11: C309.1, U57.3, U57.13, U57.14
3.3V_F12: C336.1, U62.3, U62.13, U62.14
3.3V_F13: C363.1, U67.3, U67.13, U67.14
3.3V_F14: C390.1, U72.3, U72.13, U72.14
3.3V_F15: C417.1, U77.3, U77.13, U77.14
3.3V_F16: C444.1, U82.3, U82.13, U82.14
3.3V_F17: C471.1, U87.3, U87.13, U87.14
3.3V_F18: C498.1, U92.3, U92.13, U92.14
3.3V_F19: C525.1, U97.3, U97.13, U97.14
4: J2.8, U2.24
5: D4.A, J2.12, U2.34
6: C31.2, J3.17, U10.8
7: C31.1, J3.18, U10.7
8: C30.2, J3.20, U10.5
9: C30.1, J3.19, U10.6
10: J4.11, U10.21
11: J3.9, U10.17
12: J1.8, U2.18
13: J1.7, U2.20
14: J1.9, U2.17
15: J2.11, U2.21
16: J2.6, U2.25
17: J2.7, U2.27
18: J2.13, U2.35
19: J2.15, U2.38
20: J3.7, U10.20
21: J2.19, U2.42
22: J2.16, U2.39
23: J2.14, U2.36
24: J3.8, U10.18
25: J1.12, U2.14
26: J1.11, U2.15
27: J1.10, U2.16
28: J3.10, U10.16
29: J3.11, U10.15
30: J4.16, U10.39
31: J4.19, U10.42
32: J4.15, U10.38
32K_XN: C26.2, J1.15, U2.13, Y2.P$2
32K_XN1: C53.2, J3.15, U10.13, Y4.P$2
32K_XN2: C80.2, J5.15, U15.13, Y6.P$2
32K_XN3: C107.2, J7.15, U20.13, Y8.P$2
32K_XN4: C134.2, J9.15, U25.13, Y10.P$2
32K_XN5: C161.2, J11.15, U30.13, Y12.P$2
32K_XN6: C188.2, J13.15, U35.13, Y14.P$2
32K_XN7: C215.2, J15.15, U40.13, Y16.P$2
32K_XN8: C242.2, J17.15, U45.13, Y18.P$2
32K_XN9: C269.2, J19.15, U50.13, Y20.P$2
32K_XN10: C296.2, J21.15, U55.13, Y22.P$2
32K_XN11: C323.2, J23.15, U60.13, Y24.P$2
32K_XN12: C350.2, J25.15, U65.13, Y26.P$2
32K_XN13: C377.2, J27.15, U70.13, Y28.P$2
32K_XN14: C404.2, J29.15, U75.13, Y30.P$2
32K_XN15: C431.2, J31.15, U80.13, Y32.P$2
32K_XN16: C458.2, J33.15, U85.13, Y34.P$2
32K_XN17: C485.2, J35.15, U90.13, Y36.P$2
32K_XN18: C512.2, J37.15, U95.13, Y38.P$2
32K_XN19: C539.2, J39.15, U100.13, Y40.P$2
32K_XP: C9.2, J1.16, U2.12, Y2.P$1
32K_XP1: C52.2, J3.16, U10.12, Y4.P$1
32K_XP2: C79.2, J5.16, U15.12, Y6.P$1
32K_XP3: C106.2, J7.16, U20.12, Y8.P$1
32K_XP4: C133.2, J9.16, U25.12, Y10.P$1
32K_XP5: C160.2, J11.16, U30.12, Y12.P$1
32K_XP6: C187.2, J13.16, U35.12, Y14.P$1
32K_XP7: C214.2, J15.16, U40.12, Y16.P$1
32K_XP8: C241.2, J17.16, U45.12, Y18.P$1
32K_XP9: C268.2, J19.16, U50.12, Y20.P$1
32K_XP10: C295.2, J21.16, U55.12, Y22.P$1
32K_XP11: C322.2, J23.16, U60.12, Y24.P$1
32K_XP12: C349.2, J25.16, U65.12, Y26.P$1
32K_XP13: C376.2, J27.16, U70.12, Y28.P$1
32K_XP14: C403.2, J29.16, U75.12, Y30.P$1
32K_XP15: C430.2, J31.16, U80.12, Y32.P$1
32K_XP16: C457.2, J33.16, U85.12, Y34.P$1
32K_XP17: C484.2, J35.16, U90.12, Y36.P$1
32K_XP18: C511.2, J37.16, U95.12, Y38.P$1
32K_XP19: C538.2, J39.16, U100.12, Y40.P$1
33: J4.13, U10.35
34: J1.14, U2.10
35: J1.13, U2.11
36: C1.2, J1.20, U2.5
37: C1.1, J1.19, U2.6
38: C2.1, J1.18, U2.7
39: C2.2, J1.17, U2.8
40: J4.6, U10.25
41: D8.A, J4.12, U10.34
42: J4.8, U10.24
43: J4.10, U10.22
44: J3.12, U10.14
45: J4.9, Q4.6, R26.1, S4.3, S4.4, U10.23
46: J4.7, U10.27
47: J4.14, U10.36
48: J5.14, U15.10
49: J5.13, U15.11
50: C58.2, J5.17, U15.8
51: C58.1, J5.18, U15.7
52: C57.2, J5.20, U15.5
53: C57.1, J5.19, U15.6
54: J6.11, U15.21
55: J5.9, U15.17
56: J5.7, U15.20
57: J5.8, U15.18
58: J5.10, U15.16
59: J5.11, U15.15
60: J6.16, U15.39
61: J6.19, U15.42
62: J6.15, U15.38
63: J6.13, U15.35
64: J6.6, U15.25
65: D12.A, J6.12, U15.34
66: J6.8, U15.24
67: J6.10, U15.22
68: J5.12, U15.14
69: J6.9, Q6.6, R39.1, S6.3, S6.4, U15.23
70: J6.7, U15.27
71: J6.14, U15.36
72: J7.14, U20.10
73: J7.13, U20.11
74: C85.2, J7.17, U20.8
75: C85.1, J7.18, U20.7
76: C84.2, J7.20, U20.5
77: C84.1, J7.19, U20.6
78: J8.11, U20.21
79: J7.9, U20.17
80: J7.7, U20.20
81: J7.8, U20.18
82: J7.10, U20.16
83: J7.11, U20.15
84: J8.16, U20.39
85: J8.19, U20.42
86: J8.15, U20.38
87: J8.13, U20.35
88: J8.6, U20.25
89: D16.A, J8.12, U20.34
90: J8.8, U20.24
91: J8.10, U20.22
92: J7.12, U20.14
93: J8.9, Q8.6, R52.1, S8.3, S8.4, U20.23
94: J8.7, U20.27
95: J8.14, U20.36
96: J9.14, U25.10
97: J9.13, U25.11
98: C112.2, J9.17, U25.8
99: C112.1, J9.18, U25.7
100: C111.2, J9.20, U25.5
101: C111.1, J9.19, U25.6
102: J10.11, U25.21
103: J9.9, U25.17
104: J9.7, U25.20
105: J9.8, U25.18
106: J9.10, U25.16
107: J9.11, U25.15
108: J10.16, U25.39
109: J10.19, U25.42
110: J10.15, U25.38
111: J10.13, U25.35
112: J10.6, U25.25
113: D20.A, J10.12, U25.34
114: J10.8, U25.24
115: J10.10, U25.22
116: J9.12, U25.14
117: J10.9, Q10.6, R65.1, S10.3, S10.4, U25.23
118: J10.7, U25.27
119: J10.14, U25.36
120: J11.14, U30.10
121: J11.13, U30.11
122: C139.2, J11.17, U30.8
123: C139.1, J11.18, U30.7
124: C138.2, J11.20, U30.5
125: C138.1, J11.19, U30.6
126: J12.11, U30.21
127: J11.9, U30.17
128: J11.7, U30.20
129: J11.8, U30.18
130: J11.10, U30.16
131: J11.11, U30.15
132: J12.16, U30.39
133: J12.19, U30.42
134: J12.15, U30.38
135: J12.13, U30.35
136: J12.6, U30.25
137: D24.A, J12.12, U30.34
138: J12.8, U30.24
139: J12.10, U30.22
140: J11.12, U30.14
141: J12.9, Q12.6, R78.1, S12.3, S12.4, U30.23
142: J12.7, U30.27
143: J12.14, U30.36
144: J13.14, U35.10
145: J13.13, U35.11
146: C166.2, J13.17, U35.8
147: C166.1, J13.18, U35.7
148: C165.2, J13.20, U35.5
149: C165.1, J13.19, U35.6
150: J14.11, U35.21
151: J13.9, U35.17
152: J13.7, U35.20
153: J13.8, U35.18
154: J13.10, U35.16
155: J13.11, U35.15
156: J14.16, U35.39
157: J14.19, U35.42
158: J14.15, U35.38
159: J14.13, U35.35
160: J14.6, U35.25
161: D28.A, J14.12, U35.34
162: J14.8, U35.24
163: J14.10, U35.22
164: J13.12, U35.14
165: J14.9, Q14.6, R91.1, S14.3, S14.4, U35.23
166: J14.7, U35.27
167: J14.14, U35.36
168: J15.14, U40.10
169: J15.13, U40.11
170: C193.2, J15.17, U40.8
171: C193.1, J15.18, U40.7
172: C192.2, J15.20, U40.5
173: C192.1, J15.19, U40.6
174: J16.11, U40.21
175: J15.9, U40.17
176: J15.7, U40.20
177: J15.8, U40.18
178: J15.10, U40.16
179: J15.11, U40.15
180: J16.16, U40.39
181: J16.19, U40.42
182: J16.15, U40.38
183: J16.13, U40.35
184: J16.6, U40.25
185: D32.A, J16.12, U40.34
186: J16.8, U40.24
187: J16.10, U40.22
188: J15.12, U40.14
189: J16.9, Q16.6, R104.1, S16.3, S16.4, U40.23
190: J16.7, U40.27
191: J16.14, U40.36
192: J17.14, U45.10
193: J17.13, U45.11
194: C220.2, J17.17, U45.8
195: C220.1, J17.18, U45.7
196: C219.2, J17.20, U45.5
197: C219.1, J17.19, U45.6
198: J18.11, U45.21
199: J17.9, U45.17
200: J17.7, U45.20
201: J17.8, U45.18
202: J17.10, U45.16
203: J17.11, U45.15
204: J18.16, U45.39
205: J18.19, U45.42
206: J18.15, U45.38
207: J18.13, U45.35
208: J18.6, U45.25
209: D36.A, J18.12, U45.34
210: J18.8, U45.24
211: J18.10, U45.22
212: J17.12, U45.14
213: J18.9, Q18.6, R117.1, S18.3, S18.4, U45.23
214: J18.7, U45.27
215: J18.14, U45.36
216: J19.14, U50.10
217: J19.13, U50.11
218: C247.2, J19.17, U50.8
219: C247.1, J19.18, U50.7
220: C246.2, J19.20, U50.5
221: C246.1, J19.19, U50.6
222: J20.11, U50.21
223: J19.9, U50.17
224: J19.7, U50.20
225: J19.8, U50.18
226: J19.10, U50.16
227: J19.11, U50.15
228: J20.16, U50.39
229: J20.19, U50.42
230: J20.15, U50.38
231: J20.13, U50.35
232: J20.6, U50.25
233: D40.A, J20.12, U50.34
234: J20.8, U50.24
235: J20.10, U50.22
236: J19.12, U50.14
237: J20.9, Q20.6, R130.1, S20.3, S20.4, U50.23
238: J20.7, U50.27
239: J20.14, U50.36
240: J21.14, U55.10
241: J21.13, U55.11
242: C274.2, J21.17, U55.8
243: C274.1, J21.18, U55.7
244: C273.2, J21.20, U55.5
245: C273.1, J21.19, U55.6
246: J22.11, U55.21
247: J21.9, U55.17
248: J21.7, U55.20
249: J21.8, U55.18
250: J21.10, U55.16
251: J21.11, U55.15
252: J22.16, U55.39
253: J22.19, U55.42
254: J22.15, U55.38
255: J22.13, U55.35
256: J22.6, U55.25
257: D44.A, J22.12, U55.34
258: J22.8, U55.24
259: J22.10, U55.22
260: J21.12, U55.14
261: J22.9, Q22.6, R143.1, S22.3, S22.4, U55.23
262: J22.7, U55.27
263: J22.14, U55.36
264: J23.14, U60.10
265: J23.13, U60.11
266: C301.2, J23.17, U60.8
267: C301.1, J23.18, U60.7
268: C300.2, J23.20, U60.5
269: C300.1, J23.19, U60.6
270: J24.11, U60.21
271: J23.9, U60.17
272: J23.7, U60.20
273: J23.8, U60.18
274: J23.10, U60.16
275: J23.11, U60.15
276: J24.16, U60.39
277: J24.19, U60.42
278: J24.15, U60.38
279: J24.13, U60.35
280: J24.6, U60.25
281: D48.A, J24.12, U60.34
282: J24.8, U60.24
283: J24.10, U60.22
284: J23.12, U60.14
285: J24.9, Q24.6, R156.1, S24.3, S24.4, U60.23
286: J24.7, U60.27
287: J24.14, U60.36
288: J25.14, U65.10
289: J25.13, U65.11
290: C328.2, J25.17, U65.8
291: C328.1, J25.18, U65.7
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

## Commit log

2016-04-11 Initial commit of hardware
    [esp32-thing.brd, esp32-thing.sch]
2016-04-11 Cleaning up schematic.
    [esp32-thing.brd, esp32-thing.sch]
2016-04-21 Adding PROD_IDs to new parts, adding new parts to temp library.
    [esp32-thing.brd, esp32-thing.sch]
2016-04-21 Misc changes after running through checklist.
    [esp32-thing.brd, esp32-thing.sch]
2016-04-22 Adding name, value to C1, C2. Updating IC value.
    [esp32-thing.brd, esp32-thing.sch]
2016-05-13 Fixing NPN pin assignments, flash HD and SWP pin routes.
    [esp32-thing.brd, esp32-thing.sch]
2016-05-17 Swapping ESP32 in for ESP31B, adding pull-up to GPIO0
    [esp32-thing.brd, esp32-thing.sch]
2016-05-25 Fixing reset pin wiring.
    [esp32-thing.brd, esp32-thing.sch]
2016-09-14 Fixing ESP32 pin map, re-routing RX, TX
    [esp32-thing.brd, esp32-thing.sch]
2016-09-15 Re-routing i/o traces to get better ground fill.
    [esp32-thing.brd, esp32-thing.sch]
2016-09-15 Optimizing some routing.
    [esp32-thing.brd]
2016-09-15 Post-review fixes - changed C18 to 100pF
    [esp32-thing.brd, esp32-thing.sch]
2016-09-15 Post-checklist fixes.
    [esp32-thing.brd, esp32-thing.sch]
2016-09-16 Fixing v03 checklist issues.
    [esp32-thing.brd, esp32-thing.sch]
2016-10-06 Upping to v10, fixing some silk.
    [esp32-thing.brd, esp32-thing.sch]
2016-10-06 Fixing label, SJ3 silk, reinforcing connection on USB ground.
    [esp32-thing.brd]

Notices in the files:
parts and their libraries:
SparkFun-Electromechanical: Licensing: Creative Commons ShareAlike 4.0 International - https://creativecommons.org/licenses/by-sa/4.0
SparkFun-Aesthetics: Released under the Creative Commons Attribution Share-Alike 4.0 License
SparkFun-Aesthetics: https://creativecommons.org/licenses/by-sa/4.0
